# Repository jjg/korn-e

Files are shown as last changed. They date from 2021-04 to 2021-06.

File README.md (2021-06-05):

# korn-e

# Notes

Quickly scratching-out notes for building this as it's been a bit of a nightmare.

Using Adafruit's [tinyisp](https://learn.adafruit.com/usbtinyisp) to program the Atmega328p once its in the breakout board doesn't work out-of-the box using the [Arduino](https://www.arduino.cc/) IDE.  Instead, you have to generate a .hex file, and then upload it manually using [avrdude](http://www.nongnu.org/avrdude/).

To generate the .hex file, click the Sketch menu and select Export compiled Binary.  This will write out two .hex files in the [firmware](./firmware/arduino/firmware) directory.

Next load the .hex file onto the Atmega328p using avrdude:

```
avrdude -c usbtiny -p atmega328p -B10 -U flash:w:firmware.ino.standard.hex
```

The secret ingredient is the `-B10` flag, without this upload errors occur and you're screwed (this is what happens when you try to use the Arduino IDE directly).

# References

* https://github.com/jjg/laserharp/blob/main/firmware.py
* https://docs.micropython.org/en/latest/esp8266/tutorial/neopixel.html
* https://www.makerfabs.cc/article/micropython-esp32-tutorial-interfacing-ultrasonic-sensor.html
* https://github.com/jjg/linebird/blob/main/journal.md
* https://github.com/miketeachman/micropython-esp32-i2s-examples
* https://wiki.dfrobot.com/DFPlayer_PRO_SKU_DFR0768
* https://github.com/DFRobot/DFRobot_DF1201S
* https://create.arduino.cc/projecthub/robocircuits/neopixel-tutorial-1ccfb9
* https://github.com/CharlesJGantt/Illuminate-NeoPixels-using-an-HC-SR04-Distance-Sensor-and-an-Arduino/blob/master/NeoPixels_HC-SR04.ino
* https://github.com/FastLED/FastLED/wiki/Basic-usage
* https://www.arduino.cc/reference/en/language/functions/advanced-io/pulsein/
* https://www.tutorialspoint.com/arduino/arduino_ultrasonic_sensor.htm
* http://www.martyncurrey.com/arduino-atmega-328p-fuse-settings/
* https://forums.adafruit.com/viewtopic.php?t=64694
* http://www.ladyada.net/learn/avr/avrdude.html
* https://learn.adafruit.com/usbtinyisp/avrdude
* https://www.instructables.com/Program-Arduino-Mini-05-with-FTDI-Basic/

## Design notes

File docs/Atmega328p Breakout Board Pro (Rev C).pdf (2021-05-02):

## Atmega328p Breakout Board Pro (Revision C) Documentation

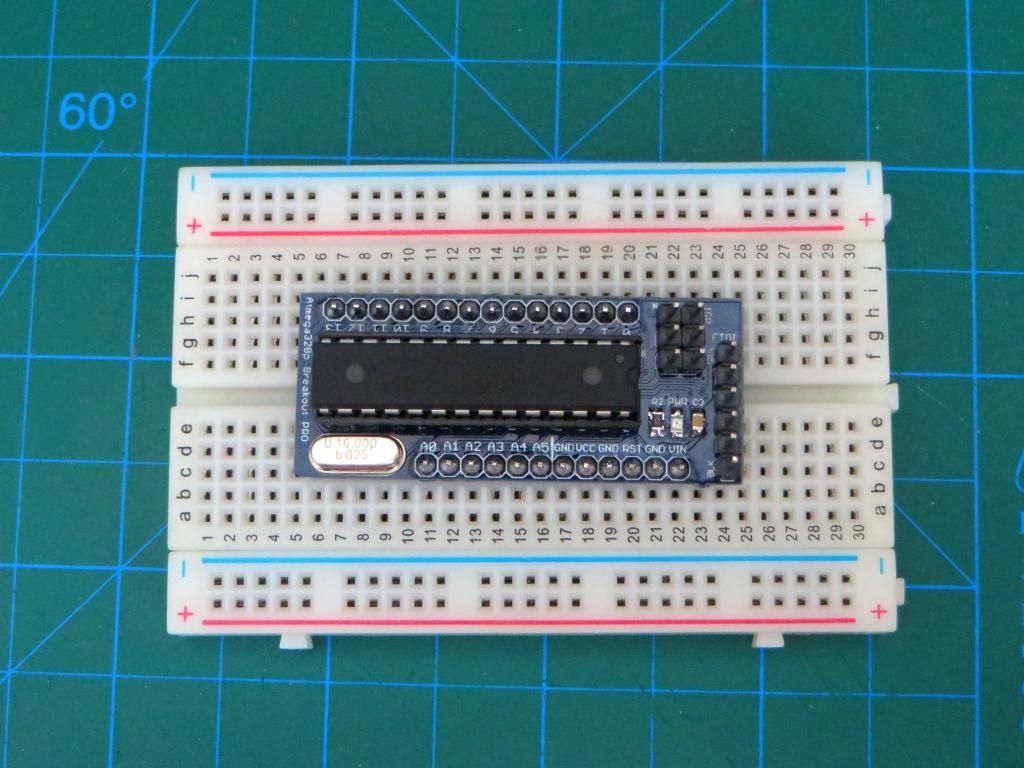
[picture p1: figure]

Last updated: January 26, 2017

## Description

The Atmega328p Breakout Board is a small circuit board that can help you shrink your Arduino Uno based project.

Product page: https://www.tindie.com/products/mwhelectronics/atmega328p-breakout-board/.

## Package Contents

- 1 x Atmega328p Breakout Board Pro

The Atmega328p microcontroller and headers are not included.

## Technical Notes & Considerations

### Atmega328p Datasheet

The Breakout Board's operating ratings are the same as the actual Atmega328p microcontroller. View the datasheet for the Atmega328p microcontroller here: http://www.atmel.com/Images/Atmel-8271-8-bit-AVR-Microcontroller-ATmega48A-48PA-88A-88PA-168A-168PA-328-328P_datasheet.pdf (http://www.atmel.com/Images/Atmel-8271-8-bit-AVR-Microcontroller-ATmega48A-48PA-88A-88PA-168A-168PA-328-328P_datasheet.pdf)

The most relevant operational ratings to consider are supply voltage (1.8-5v) and current per I/O pin (20mA).

### Power Supply

The Breakout Board does not have a voltage regulator. This means that you must supply a voltage within the operating voltage rating of the Atmega328p microcontroller, which is 1.8v to 5.5v. The input voltage will affect the brightness of the power LED indicator. 5v is recommended.

The positive side of your power supply should be connected to the Vin pad. Vin is connected directly to Vcc, where Vcc can be used to bring power to components in your project if you wish.

You should only have one power supply connected to the Board at a time. Your FTDI Basic and USBtinyISP boards supply power, so they should not be connected at the same time or when there is power supplied to the Vin pin.

### Reset Pin

The reset pin is labeled RST next to a GND ground pin. Connecting these two pads together (grounding the reset pin) by the closure of a button will reset the microcontroller. If you do not need a reset button, leave the pads alone.

### Socket

Make sure your Atmega328p microcontroller is sitting in the socket properly. Line up the U-shape on the microcontroller with the one on the socket. This indicates the top of the microcontroller. Putting in the microcontroller the wrong way, or placing or removing the microcontroller while the Board is powered may cause damage.

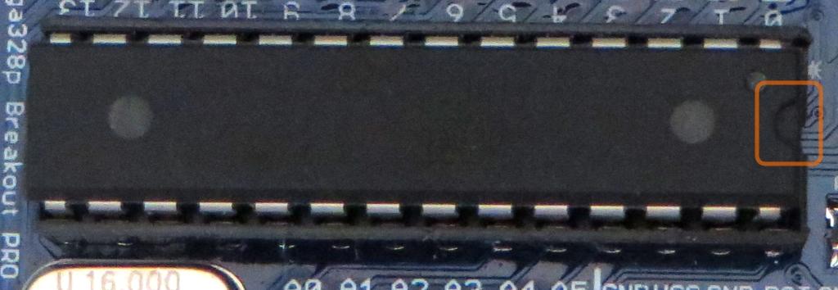
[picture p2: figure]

Push down on the microcontroller firmly so that it sits completely into the socket, while making sure the pins are lining up with the socket. Make sure no pins have been bent and that all pins are seated into each pin socket.

### A note about being Breadboard-Friendly

While the Breakout Board does fit in a breadboard, the pins are slightly misaligned so the board sits at a slight angle, as seen in the image on the first page of this document. The misalignment is not large enough to cause any difficulties in inserting the Breakout Board into the breadboard.

Placing the Breakout Board in the middle of a breadboard allows access to two breadboard pins for each pin of the Breakout Board. The angle of the board makes it difficult to access some of the pins with dupont male jumper wires but is not an issue for solid-core wire. This issue will be addressed in the future. Apologies for any inconvenience.

## Assembling the Board

### Tools You'll Need

You will need soldering tools and skills to complete your power and I/O connections. The tools you will need are:

- Safety glasses
- Soldering iron
- Cleaner for the iron: A damp sponge and/or brass cleaner
- Solder
- Wire cutter

There are plenty of guides and videos online if you are just learning how to solder. The general idea is to get both the component lead and pad on the board hot enough so that the solder melts directly to make the connection.

### Assembly Tips

- Whatever your plans are for the Board will decide how you will make your I/O connections.
- Permanently integrating it into your project?
■ Solder your wire connections directly to the board.
- Using it to prototype on a breadboard?
■ Solder male headers so that it can sit directly in a breadboard.
- Using it to prototype without a breadboard?
■ Cut some female headers to size and solder them so that you can make temporary connections, or solder male headers so that you can connect female jumper wires..

## Programming

The Atmega328p Breakout Board Pro offers three ways to program the Atmega328p microcontroller.

### Using your Arduino Uno

The simplest way to program the Atmega328p microcontroller is by using the socket on your Arduino Uno. Once programmed, all you have to do is transfer the microcontroller over to the Breakout Board.

Be very cautious placing and removing the microcontroller into and out of the socket as the pins of the microcontroller can be damaged in the process. This method is recommended for projects that are nearly complete, where you would rarely have to upload new code.

### Using your USBtinyISP

The USBtinyISP allows you to upload new code and burn the bootloader, but it does not allow for serial communication.

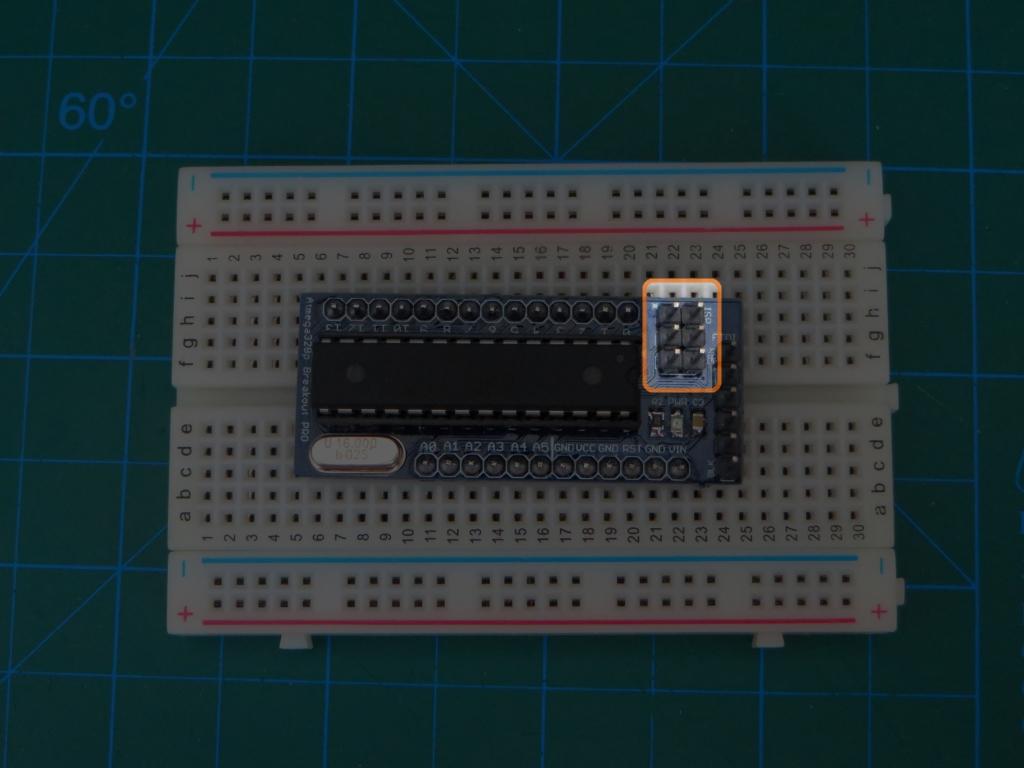
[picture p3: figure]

USBtinyISP driver install guide (by Adafruit): https://learn.adafruit.com/usbtinyisp/drivers

To upload to the Breakout Board using your USBtinyISP with the Arduino IDE:

1. In the Arduino IDE, select Tools>Programmer>USBtinyISP.
2. Connect the USBtinyISP 6-pin ribbon cable connector to the ISP header on the Breakout Board. Make sure it is in the correct orientation. See the pinout to the left. If unsure, the easiest way is to find where Vcc by measuring for +5V across those pins.
3. Hold shift as you click the Upload button, or click Sketch>Upload Using Programmer.

Note that, after you have used the USBtinyISP to upload a sketch to the Atmega328p, you must burn the bootloader to be able to upload a sketch using an Arduino Uno or FTDI Basic.

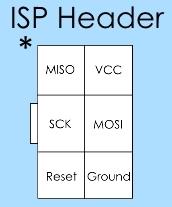
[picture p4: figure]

### Using your FTDI Basic

The FTDI Basic allows you to upload new code and have a serial connection between your computer and the Atmega328p microcontroller (great for debugging).

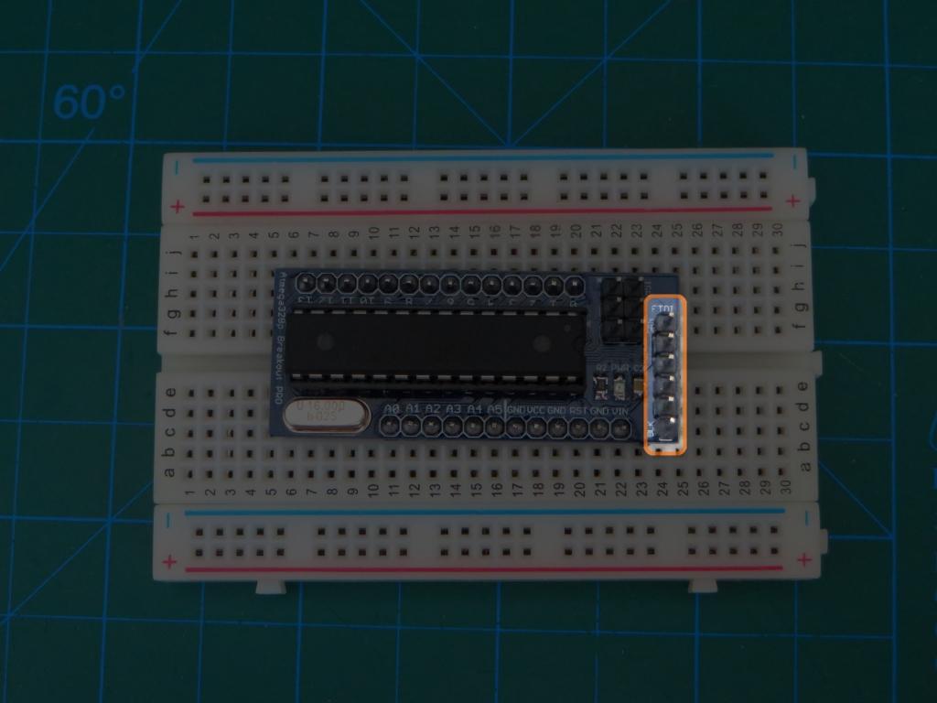
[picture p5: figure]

FTDI driver install guide (by Sparkfun): https://learn.sparkfun.com/tutorials/how-to-install-ftdi-drivers/windows---quick-and-easy

To upload to the Breakout Board using your FTDI Basic with the Arduino IDE:

1. In the Arduino IDE, select Tools>Programmer>Arduino as ISP.
2. Connect the FTDI Basic to the FTDI header on the edge of the Breakout Board. Note where the BLK (Black) and GRN (Green) labels are for the correct orientation.
3. Click the Upload button.

## Questions & Feedback

If you have any questions after reading through this document or working with the product, please let me know and I will try to help.

If you have any compliments or constructive feedback, let me know by leaving feedback on the product page or sending me a message. I am constantly working on revising products and their listings to ensure the best experience for everyone.

## Previous Documentation

### Revision B https://docs.google.com/document/d/1FHcPpH7GgUtGlA-Ypvo9dxUWRpgWTDG4NF-RLNlBpFs/edit

?usp=sharing (https://docs.google.com/document/d/1FHcPpH7GgUtGlA-Ypvo9dxUWRpgWTDG4NF-RLNlBpFs/edit?usp=sharing)

### Revision A

N/A

## Warranty Disclaimer

### Returns & Refunds

Returns are not accepted. However, full or partial refunds may be offered in cases where a manufacturing defect in the product is reported within the 30 days after the order was shipped. Refunds will not be offered if the product is soldered or modified in anyway, or if the product is incorrectly assembled or used.

### Safety

Safety should always be your top priority. Take appropriate safety precautions when assembling and using this product. Wear personal protection equipment. Keep the product away from children and pets as it may present a choking hazard. Always stay within the operating ratings of the product for your safety and for the longevity of the product. Do not leave the product unattended while powered. This product must only be used in low-power hobbyist applications.

The designers, suppliers, and manufacturers of this product shall not be held liable for any damages or losses from the use or misuse of this product.

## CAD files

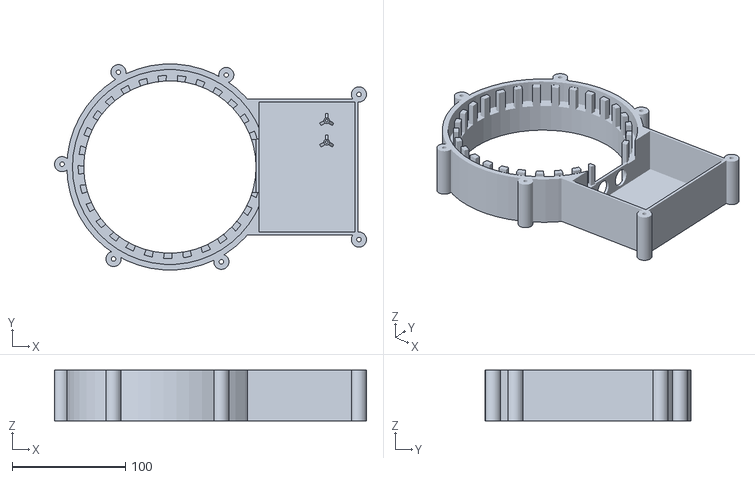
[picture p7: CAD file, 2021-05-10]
models/case.stl
276.0 x 182.0 x 45.0

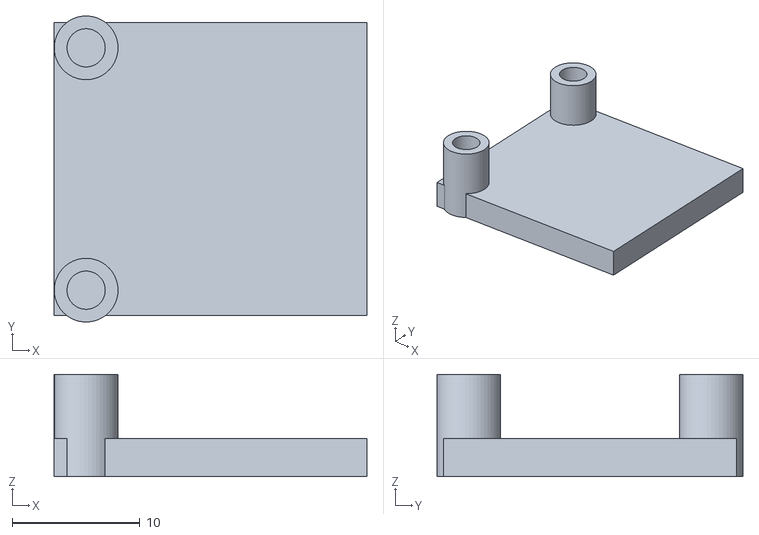
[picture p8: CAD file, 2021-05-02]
models/df_player_pro_mount.stl
24.5 x 24.0 x 8.00

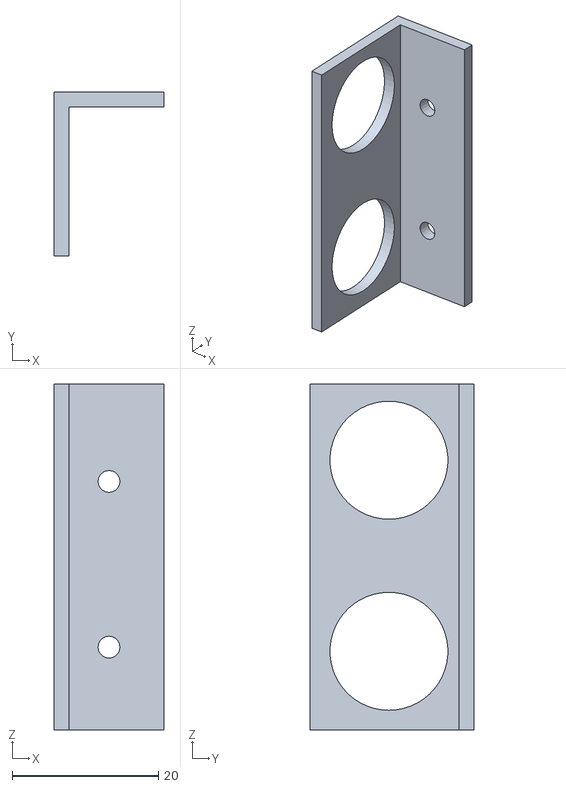
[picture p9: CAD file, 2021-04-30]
models/ping_sensor_mount.stl
15.0 x 22.4 x 47.3

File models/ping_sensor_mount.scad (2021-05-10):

module ping_sensor_mount(){

    sensor_width = 45.35;
    sensor_height = 20.38;
    sensor_depth = 15.43;
    barrel_edge = 1.8;
    barrel_between = 10.21;
    barrel_diameter = 15.94;
    barrel_height = 12.23;
    xtal_height = 3.55;
    xtal_width = 10.80;
    conn_width = 10.52;
    conn_pin_length = 5.41;
    flange_length = 15;
    flange_depth = 2;

    // sensor bounding box (minus connector)
    //cube([sensor_width, sensor_height, sensor_depth]);

    union(){
        // mounting plate
        rotate([0,-90,0]){
            difference(){
                // mounting plate
                cube([sensor_width + 2, sensor_height + 2, 2.5]);

                // barrel holes
                translate([barrel_edge+(barrel_diameter/2)+1,barrel_edge+(barrel_diameter/2)+1,-1]){
                    cylinder(r=barrel_diameter/2+.1,h=barrel_height,$fn=50);
                }
                translate([barrel_edge + barrel_between + barrel_diameter + (barrel_diameter/2)+1,barrel_edge+(barrel_diameter/2)+1,-1]){
                    cylinder(r=barrel_diameter/2+.1,h=barrel_height,$fn=50);
                }
            }
        }

        // screw flange
        translate([-2,sensor_height + 3,0]){
            rotate([0,0,-90]){
                difference(){
                    cube([flange_depth,flange_length,sensor_width + 2]);
                    
                    rotate([0,90,0]){
                        translate([-(sensor_width/2)+(sensor_width/4),flange_length/2,-flange_depth/2]){
                            cylinder(r=1.5,h=flange_depth+2, $fn=20);
                        }

                        translate([-(sensor_width/2)-(sensor_width/4),flange_length/2,-flange_depth/2]){
                            cylinder(r=1.5,h=flange_depth+2, $fn=20);
                        }
                    }
                }
            }
        }
    }
}

//ping_sensor_mount();

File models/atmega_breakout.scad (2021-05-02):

module atmega_breakout(){
    
    LENGTH = 46;
    WIDTH = 24;
    DEPTH = 5;      // default
    
    cube([LENGTH, WIDTH, DEPTH]);
}

//atmega_breakout();

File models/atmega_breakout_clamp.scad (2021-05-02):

module atmega_breakout_clamp(){
    
    $fn=30;
    
    SCREW_SHAFT_DIAMETER = 3;
    SCREW_HEAD_DIAMETER = 4;
    CHIP_WIDTH = 5;     // guess
    CHIP_LENGTH = 40;   // guess
    CHIP_HEIGHT = 10;   // guess
    CLIP_THICKNESS = 5;
    
    difference(){
        
        cube([CHIP_LENGTH+CLIP_THICKNESS, CHIP_WIDTH, CHIP_HEIGHT+CLIP_THICKNESS]);
        
        // cut-out for chip
        translate([CLIP_THICKNESS,0,0]){
            cube([CHIP_LENGTH, CHIP_WIDTH, CHIP_HEIGHT]);
        }
        
        // cut-out for screw
        translate([CLIP_THICKNESS/2,CHIP_WIDTH/2,0]){
            cylinder(r=SCREW_SHAFT_DIAMETER/2,h=CHIP_HEIGHT+CLIP_THICKNESS);
        }
    }
}

//atmega_breakout_clamp();

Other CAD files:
models/atmega_breakout_mount.scad
models/case.scad
models/df_player_pro.scad
models/df_player_pro_mount.scad
models/gusset.scad

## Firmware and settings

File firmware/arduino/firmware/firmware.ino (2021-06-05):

#include <DFRobot_PLAY.h>
#include <SoftwareSerial.h>
#include <FastLED.h>

/*
 * Firmware for the korn-e electronic cornhole hardware
 * 
 * Things to do:
 * * Initialize all the hardware
 * * Play an initial sound
 * * Illuminate some inital lights
 * * Watch for a bag in the hole
 * * Play another sound and animate the lights
 * * etc.
 */

// Enables/disables debugging over serial
#define DEBUG false

#define TRIGGER_PIN 6
#define ECHO_PIN 7
#define INSIDE_LED_DATA_PIN 5
#define OUTSIDE_LED_DATA_PIN 8
#define SOUND_RX_PIN 2
#define SOUND_TX_PIN 3
#define NUM_INSIDE_LEDS 29
#define NUM_OUTSIDE_LEDS 240
#define HOLE_SIZE 3


// Init array for leds
CRGB inside_leds[NUM_INSIDE_LEDS];
CRGB outside_leds[NUM_OUTSIDE_LEDS];

// Init serial connection to sound board
SoftwareSerial DF1201SSerial(SOUND_RX_PIN, SOUND_TX_PIN);
DFRobot_PLAY DF1201S;


void setup() {

  // Init serial port for debugging
  if(DEBUG)
    Serial.begin(115200);


  /*** Init the hardware ***/
  
  // Init sound board
  DF1201SSerial.begin(57600);
  while(!DF1201S.begin(DF1201SSerial)){
    if(DEBUG)
      Serial.println("Init failed, please check the wire connection!");
      
    delay(1000);
  }
  // TODO: Disable sound board LED
  DF1201S.setPrompt(false);
  DF1201S.switchFunction(DF1201S.MUSIC);
  DF1201S.setPlayMode(DF1201S.SINGLE);
  DF1201S.setVol(20);
  
  // Init LEDs
  FastLED.addLeds<NEOPIXEL, INSIDE_LED_DATA_PIN>(inside_leds, NUM_INSIDE_LEDS);
  FastLED.addLeds<NEOPIXEL, OUTSIDE_LED_DATA_PIN>(outside_leds, NUM_OUTSIDE_LEDS);
  
  // Init rangefinder
  pinMode(TRIGGER_PIN, OUTPUT);
  pinMode(ECHO_PIN, INPUT);
  // Prime the sensor
  pinMode(TRIGGER_PIN, OUTPUT);
  digitalWrite(TRIGGER_PIN, LOW);
  delayMicroseconds(2);
  digitalWrite(TRIGGER_PIN, HIGH);
  delayMicroseconds(10);
  digitalWrite(TRIGGER_PIN, LOW);
  
  
  /*** Self-test each component ***/

  // Self-test LEDs
  // inside
  fill_solid( &(inside_leds[0]), NUM_INSIDE_LEDS, CRGB::Green);
  // outside
  fill_solid( &(outside_leds[0]), NUM_OUTSIDE_LEDS, CRGB::Green);
  FastLED.show();
  delay(1000);
  fill_solid( &(inside_leds[0]), NUM_INSIDE_LEDS, CRGB::Black);
  fill_solid( &(outside_leds[0]), NUM_OUTSIDE_LEDS, CRGB::Black);
  FastLED.show();
  delay(1000);

  // Self-test sound
  if (DEBUG){
    Serial.println("--------------");
    Serial.print("PlayMode: ");
    Serial.println(DF1201S.getPlayMode());
    Serial.print("TotalFile: ");
    Serial.println(DF1201S.getTotalFile());
    Serial.print("Vol: ");
    Serial.println(DF1201S.getVol());
    Serial.print("FileName: ");
    Serial.println(DF1201S.getFileName());
    Serial.println("--------------");
  }
    
  // Play start-up sound
  DF1201S.playSpecFile("/fx/startup.mp3");

  // Self-test rangefinder
  // Take a reading
  long duration;
  pinMode(ECHO_PIN, INPUT);
  duration = pulseIn(ECHO_PIN, HIGH);
  if(DEBUG){
    Serial.print("Distance: ");
    Serial.println(microsecondsToInches(duration));
  }

  // Set initial LED state
  fill_solid( &(inside_leds[0]), NUM_INSIDE_LEDS, CRGB::Black);
  fill_solid( &(outside_leds[0]), NUM_OUTSIDE_LEDS, CRGB::Red);
  FastLED.show();

}

void loop() {

  // Measure distance
  long duration, inches;
  pinMode(TRIGGER_PIN, OUTPUT);
  digitalWrite(TRIGGER_PIN, LOW);
  delayMicroseconds(2);
  digitalWrite(TRIGGER_PIN, HIGH);
  delayMicroseconds(10);
  digitalWrite(TRIGGER_PIN, LOW);

  // Take a reading
  pinMode(ECHO_PIN, INPUT);
  duration = pulseIn(ECHO_PIN, HIGH);
  inches = microsecondsToInches(duration);

  if(DEBUG){
    Serial.print("Distance: ");
    Serial.println(inches);
  }

  if(inches == HOLE_SIZE){

    if(DEBUG)
      Serial.println("Score!");
    
    // Flash leds
    fill_solid( &(inside_leds[0]), NUM_INSIDE_LEDS, CRGB::Red);
    fill_solid( &(outside_leds[0]), NUM_OUTSIDE_LEDS, CRGB::Black);
    FastLED.show();

    // Play score sound (only play a sound if the previously playing sound is done)
    if(DEBUG){
      Serial.print("getCurTime: ");
      Serial.println(DF1201S.getCurTime());
      Serial.print("getTotal_time: ");
      Serial.println(DF1201S.getTotalTime());
    }

    // NOTE: This is a hack because sometimes getCurTime() != getTotalTime() even if
    // the sound has finished playing (I'm guessing this is a rounding error?)
    //if(DF1201S.getCurTime() == DF1201S.getTotalTime()){
    if(DF1201S.getTotalTime() - DF1201S.getCurTime() < 2){
      DF1201S.playSpecFile("/fx/score.mp3");
    }

    // Move dot around outside LEDs
    for(int dot = 0; dot < NUM_OUTSIDE_LEDS; dot++) { 
        outside_leds[dot] = CRGB::Red;
        FastLED.show();
        // clear this led for the next time around the loop
        outside_leds[dot] = CRGB::Black;
        delay(10);
    }
    
    delay(500);
    fill_solid( &(inside_leds[0]), NUM_INSIDE_LEDS, CRGB::Black);
    fill_solid( &(outside_leds[0]), NUM_OUTSIDE_LEDS, CRGB::Red);
    FastLED.show();
  }

}

long microsecondsToInches(long microseconds) {
   return microseconds / 74 / 2;
}

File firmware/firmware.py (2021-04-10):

import time
from machine import Pin, I2C
import neopixel
from HC_SR04 import HCSR04
import SSD1306 as ssd1306

i2c = I2C(scl=Pin(15), sda=Pin(4), freq=400000)      #Init i2c
lcd=ssd1306.SSD1306_I2C(128,64,i2c)
sensor = HCSR04(trigger_pin=13, echo_pin=12,echo_timeout_us=1000000)
np = neopixel.NeoPixel(Pin(14), 2)

# Hole size in mm
TRIGGER_DISTANCE = 150

score = 0

try:
    while True:

        distance = sensor.distance_mm()
        #print(distance)

        if distance < TRIGGER_DISTANCE:
            score += 1

            print("*** POINT SCORED! ***")

            # Display the score on the display
            lcd.fill(0)
            lcd.text("SCORE!",30,20)
            lcd.text(str(score),30,40)
            #lcd.text("Distance:",30,20)
            #lcd.text(str(distance),30,40)
            lcd.show()

            # TODO: Flash the LEDs

            np[0] = (0, 255, 0)
            np[1] = (0,0,0)
            np.write()
            time.sleep(.25)
            np[0] = (0,0,0)
            np[1] = (0,255,0)
            np.write()
            time.sleep(.25)
            np[0] = (0,255,0)
            np[1] = (0,0,0)
            np.write()
            time.sleep(.25)
            np[0] = (0,0,0)
            np[1] = (0,0,0)
            np.write()

except KeyboardInterrupt:
       pass

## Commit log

2021-04-10 Got led's working
2021-04-13 Initial model for the case.
    [case.scad, case.stl]
2021-04-24 Switching to atmega.
2021-04-25 Don't interrupt the sound if it's already playing.
2021-05-01 Add sensor mount to base.
    [case.scad, ping_sensor_mount.scad]
2021-05-02 Sensor mount tweaks.
    [case.scad, ping_sensor_mount.scad]
2021-05-02 Begin working on a mount for the audio module.
    [case.scad, df_player_pro.scad, df_player_pro_mount.scad]
2021-05-02 More docs and WIP atmega breakout mount.
    [atmega_breakout.scad, atmega_breakout_mount.scad, df_player_pro_mount.scad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]
2021-05-02 Another approach to mounting the atmega breakout and assembling the pieces.
    [atmega_breakout.scad, atmega_breakout_clamp.scad, atmega_breakout_mount.scad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]
2021-05-02 Added mountpoints and adjusting internal layout.
    [case.scad]
2021-05-05 Added countersinks and adjusted size for 2 inch screws.
    [case.scad]
2021-05-06 Adjust sound board mount and clean-up sensor area.
    [case.scad, df_player_pro_mount.scad]
2021-05-10 Add gussets to audio board and tweak various other factors.
    [case.scad, case.stl, df_player_pro_mount.scad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]
